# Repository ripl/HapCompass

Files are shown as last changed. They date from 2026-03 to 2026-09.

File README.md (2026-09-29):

<div align="center">
  <h1>HapCompass: A Rotational Haptic Device for Contact-Rich Robotic Teleoperation</h1>

  <p>
    <a href="https://vincent-tann.github.io">Xiangshan Tan</a><sup>1</sup>,
    <a href="https://scholar.google.com/citations?user=DeQM4Z4AAAAJ&hl=en">Jingtian Ji</a><sup>1</sup>,
    <a href="http://tianchong-jiang.github.io/">Tianchong Jiang</a><sup>1</sup>,
    <a href="https://plopes.org/">Pedro Lopes</a><sup>2</sup>,
    <a href="https://home.ttic.edu/~mwalter/">Matthew R. Walter</a><sup>1</sup>
  </p>

  <p>
    <sup>1</sup>Toyota Technological Institute at Chicago (TTIC),
    <sup>2</sup>University of Chicago
  </p>

  <p><em>ICRA 2026</em></p>

  <p>
    <a href="https://ripl.github.io/HapCompass/">Project Page</a> |
    <a href="https://arxiv.org/abs/2603.30042">Paper</a> |
    <a href="https://github.com/ripl/HapCompass/tree/main/hardware">Hardware</a>
  </p>
</div>

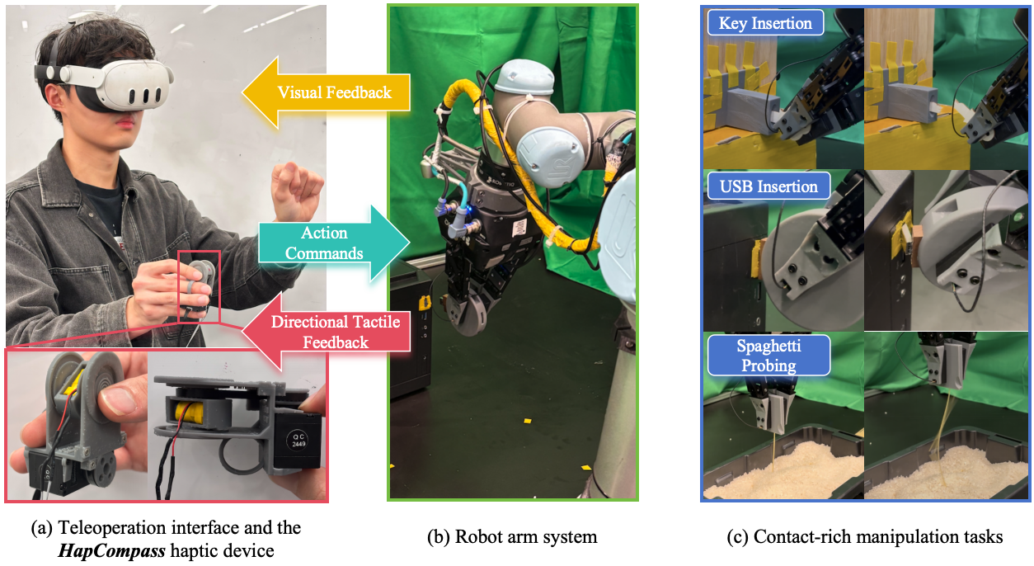
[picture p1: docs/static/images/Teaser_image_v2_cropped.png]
HapCompass teaser


## Overview
***HapCompass*** is a wearable haptic device for contact-rich robotic teleoperation that renders 2D directional cues by **mechanically rotating a single linear resonant actuator (LRA)**, whose asymmetric vibration provides directional haptic feedback. By mapping the robot's tactile measurements into directional feedback for the operator, it improves teleoperation performance on contact-rich tasks and leads to higher-quality demonstrations for imitation learning.

## TODO

### Webpage

- [x] ~~Build the project webpage~~
- [x] ~~Upload a policy rollout video~~
- [x] ~~Add an arXiv link~~

### Hardware

- [x] ~~Upload the Fusion source design and STL files~~
- [x] ~~Write BOM~~
- [x] ~~Write assembly instructions~~
<!-- - [ ] Write "Modifying Source Design" -->

<!--
### Software

- [ ] Upload the code for device control
- [ ] Upload the code for tactile mapping
- [ ] Upload the code for teleoperation
-->

## Hardware

Bill of materials (BOM), assembly instructions, editable source design (.f3z), and printable parts (.stl) can be found in the [`hardware/`](hardware/) directory.

## BibTeX

```bibtex
@inproceedings{tan2026hapcompass,
  author    = {Tan, Xiangshan and Ji, Jingtian and Jiang, Tianchong and Lopes, Pedro and Walter, Matthew R.},
  title     = {HapCompass: A Rotational Haptic Device for Contact-Rich Robotic Teleoperation},
  booktitle = {Proceedings of the IEEE International Conference on Robotics and Automation (ICRA)},
  year      = {2026},
}
```

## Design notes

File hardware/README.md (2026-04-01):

## Contents

- [Introduction](#introduction)
- [Bill of Materials (BOM)](#bill-of-materials-bom)
- [3D Printing Parts](#3d-printing-parts)
- [Critical Dimensions](#critical-dimensions)
- [Mechanical Assembly](#mechanical-assembly)
- [Electronic Assembly](#electronic-assembly)
- [Modifying the Source Design](#modifying-the-source-design)

## Introduction

This document provides the hardware documentation for HapCompass.
Please note that we made slight modifications to the version described in the paper to improve the mechanical stability of the device.

## Bill of Materials (BOM)

<table>
  <tr>
    <th>Name</th>
    <th>Quantity</th>
    <th>Specifications</th>
    <th>Image</th>
    <th>Link</th>
    <th>Price (USD)</th>
    <th>Notes</th>
  </tr>
  <tr>
    <td>LRA</td>
    <td>1</td>
    <td>Titan Haptics TacHammer DRAKE LFi (4ohm)</td>
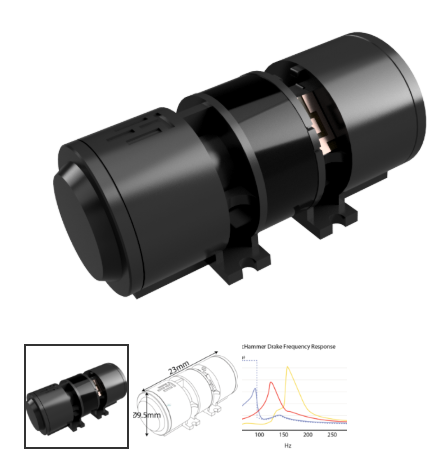
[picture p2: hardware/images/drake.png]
    <td></td>
    <td><a href="https://titanhaptics.com/drake/">Product Link</a></td>
    <td>$180/4 pieces</td>
    <td></td>
  </tr>
  <tr>
    <td>Servo Motor</td>
    <td>1</td>
    <td>Dynamixel XL330-M077-T</td>
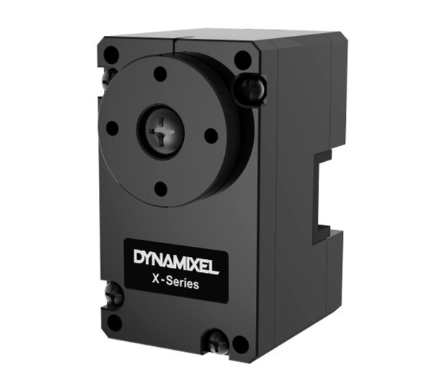
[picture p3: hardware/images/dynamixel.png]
    <td></td>
    <td><a href="https://robotis.us/dynamixel-xl330-m077-t/">Product Link</a></td>
    <td>$27.49</td>
    <td></td>
  </tr>
  <tr>
    <td>Driving Belt</td>
    <td>1</td>
    <td>MXL trade size, width 1/8'', outer circle 5.6'', 70 teeth, pitch 0.08''
    <td></td>
    <td><a href="https://www.mcmaster.com/products/1679k71/">Product Link</a></td>
    <td>$1.63</td>
    <td></td>
  </tr>
  <tr>
    <td>Ball Bearing</td>
    <td>2</td>
    <td>Inner diameter 5mm, outer diameter 8mm, width 2.5mm</td>
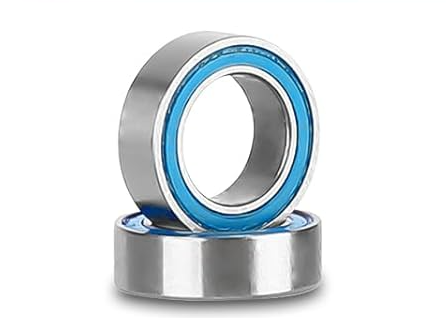
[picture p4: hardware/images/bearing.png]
    <td></td>
    <td><a href="https://www.amazon.com/dp/B0DNT3ZKY6">Product Link</a></td>
    <td>$14/1 pack</td>
    <td></td>
  </tr>
  <tr>
    <td>O-ring</td>
    <td>2</td>
    <td>Inner diameter 20mm, outer diameter 22mm, width 1mm</td>
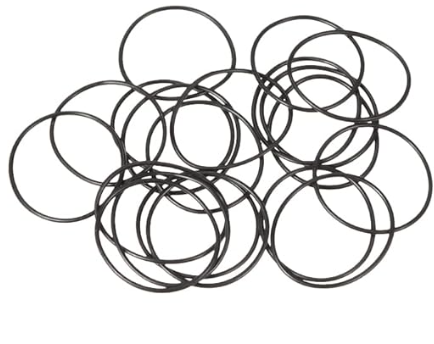
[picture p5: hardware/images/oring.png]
    <td></td>
    <!-- <td><a href="https://www.amazon.com/dp/B07FRCKJQG?th=1">Product Link</a></td> -->
    <td><a href="https://www.amazon.com/uxcell-22mmx1mm-Nitrile-Resistant-Grommets/dp/B01N8RPR5X">Product Link</a></td>
    <!-- <td>$7.09/1 pack</td> -->
    <td>$6.49/1 pack</td>
    <td>Optional</td>
  </tr>
  <tr>
    <td>Screws & Nuts</td>
    <td>3</td>
    <td>M2*4mm</td>
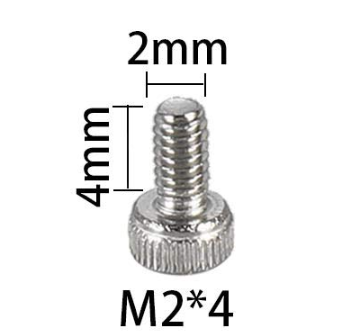
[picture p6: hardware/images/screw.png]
    <td></td>
    <td><a href=https://www.amazon.com/HanTof-Washers-Assortment-Machine-Stainless/dp/B082XRX17Z?th=1">Product Link</a></td>
    <td>-</td>
    <td></td>
  </tr>
  <tr>
    <td>Audio Amplifier Board</td>
    <td>1</td>
    <td>PAM8406 Amplifier Board 5V</td>
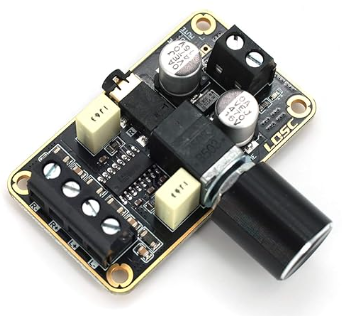
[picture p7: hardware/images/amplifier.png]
    <td></td>
    <td><a href="https://www.amazon.com/DEVMO-Amplifier-PAM8406-Digital-Channel/dp/B0899X1Y5X/?th=1">Product Link</a></td>
    <td>$13</td>
    <td></td>
  </tr>
  <tr>
    <td>Servo Driver Board</td>
    <td>1</td>
    <td>Waveshare Serial Bus Servo Driver Board</td>
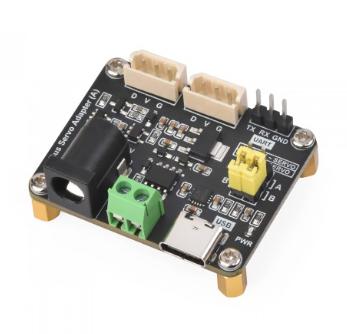
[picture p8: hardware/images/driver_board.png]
    <td></td>
    <td><a href="https://www.waveshare.com/product/bus-servo-adapter-a.htm">Product Link</a></td>
    <td>$5</td>
    <td></td>
  </tr>
</table>

## 3D Printing Parts

We printed all parts using a Formlabs Form 3 printer (using Grey resin material, 0.050mm layer thickness). We provide the `.stl` files of all parts under [`stl/`](stl/) folder.

<table>
  <tr>
    <th>Name</th>
    <th>Quantity</th>
    <th>stl file</th>
    <th>Image</th>
  </tr>
  <tr>
    <td>Rotor</td>
    <td>1</td>
    <td><a href="./stl/Rotor_bare_pulley.stl">Rotor_bare_pulley.stl</a></td>
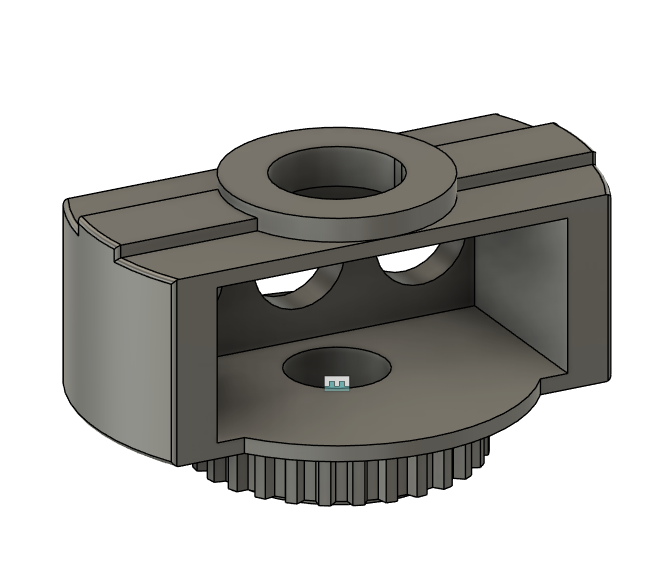
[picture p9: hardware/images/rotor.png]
    <td></td>
  </tr>

  <tr>
    <td>Motor Pulley</td>
    <td>1</td>
    <td><a href="./stl/Motor_Pulley.stl">Motor_Pulley.stl</a></td>
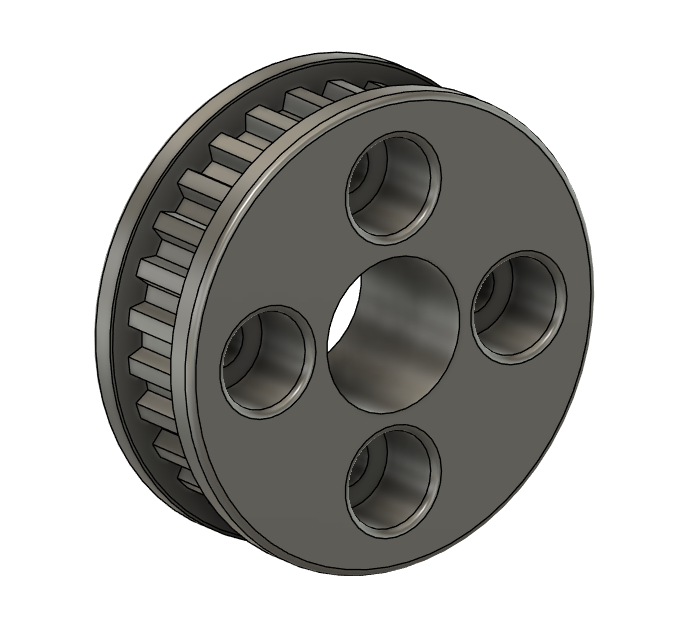
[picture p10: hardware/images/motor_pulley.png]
    <td></td>
  </tr>

  <tr>
    <td>Shell - Upper Outer</td>
    <td>1</td>
    <td><a href="./stl/Shell_upper_outside.stl">Shell_upper_outside.stl</a></td>
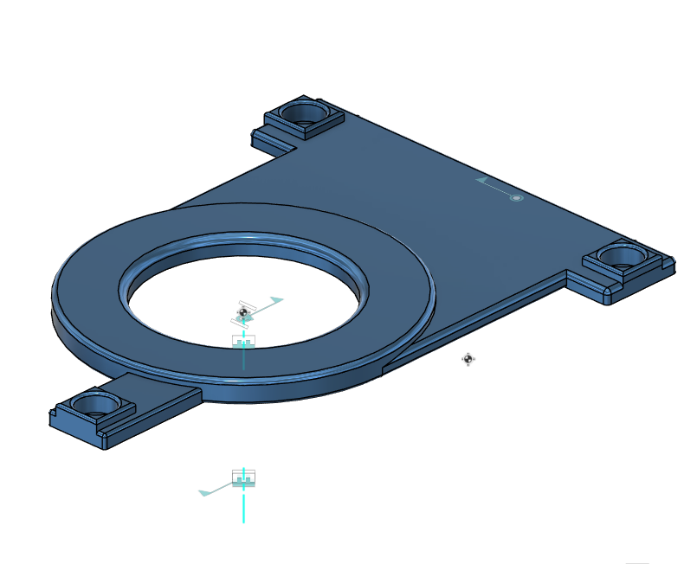
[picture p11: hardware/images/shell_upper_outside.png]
    <td></td>
  </tr>

  <tr>
    <td>Shell - Upper Inner</td>
    <td>1</td>
    <td><a href="./stl/Shell_upper_inside.stl">Shell_upper_inside.stl</a></td>
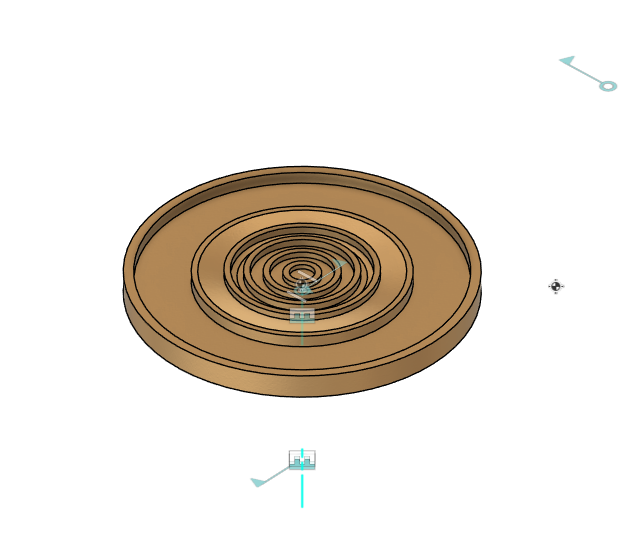
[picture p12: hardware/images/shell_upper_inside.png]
    <td></td>
  </tr>

  <tr>
    <td>Shell - Bottom Outer</td>
    <td>1</td>
    <td><a href="./stl/Shell-bottom-outside.stl">Shell-bottom-outside.stl</a></td>
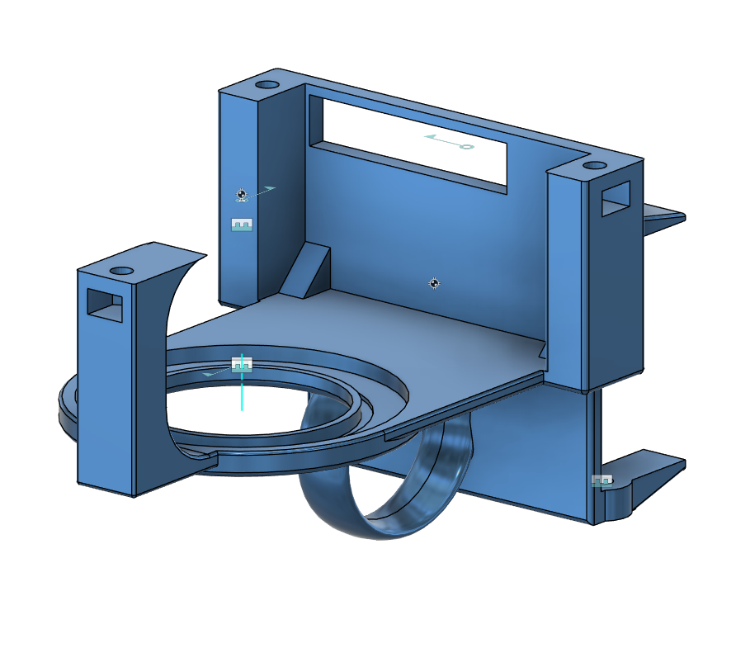
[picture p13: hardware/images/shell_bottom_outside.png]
    <td></td>
  </tr>

  <tr>
    <td>Shell - Bottom Inner</td>
    <td>1</td>
    <td><a href="./stl/Shell-bottom-inside.stl">Shell-bottom-inside.stl</a></td>
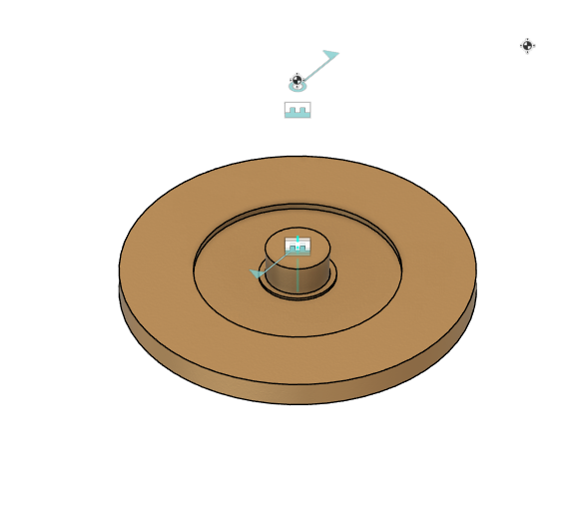
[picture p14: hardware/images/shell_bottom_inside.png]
    <td></td>
  </tr>
</table>

## Critical Dimensions

Some dimensions of the HapCompass are critical to vibration transmission. If the fit is too tight, the device may be difficult or impossible to assemble; if it is too loose, a significant portion of the vibration energy may dissipate before reaching the user's fingertip.

The effective vibration transmission path is: 
- LRA -> Rotor -> Ball Bearings -> Inner Shells (yellow) -> Fingertip

Therefore, the dimensions shown in the figure below are critical to vibration transmission:

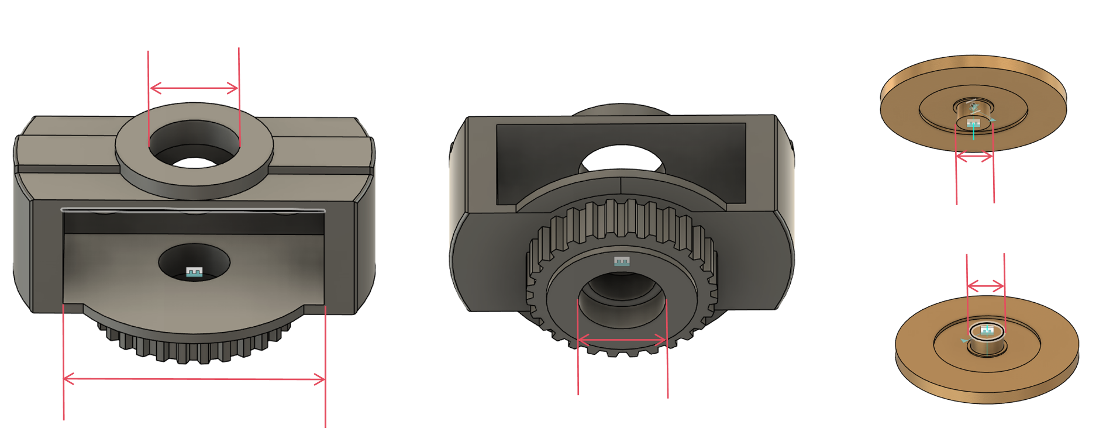
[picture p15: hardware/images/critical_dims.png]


Due to hardware variations, such as differences between 3D printers or slight variations in bearing diameter, you *might* need to adjust these dimensions. If you find that:
- the fit is so tight that assembly is almost impossible; or
- the fit is loose enough that some parts can move slightly along these dimensions (for example, the LRA can move slightly along its vibration axis inside the rotor),

then you can adjust these dimensions by [modifying the source design](#modifying-the-source-design).

## Mechanical Assembly

Step 1: Attach the two bearings and the two inner shells to the rotor.

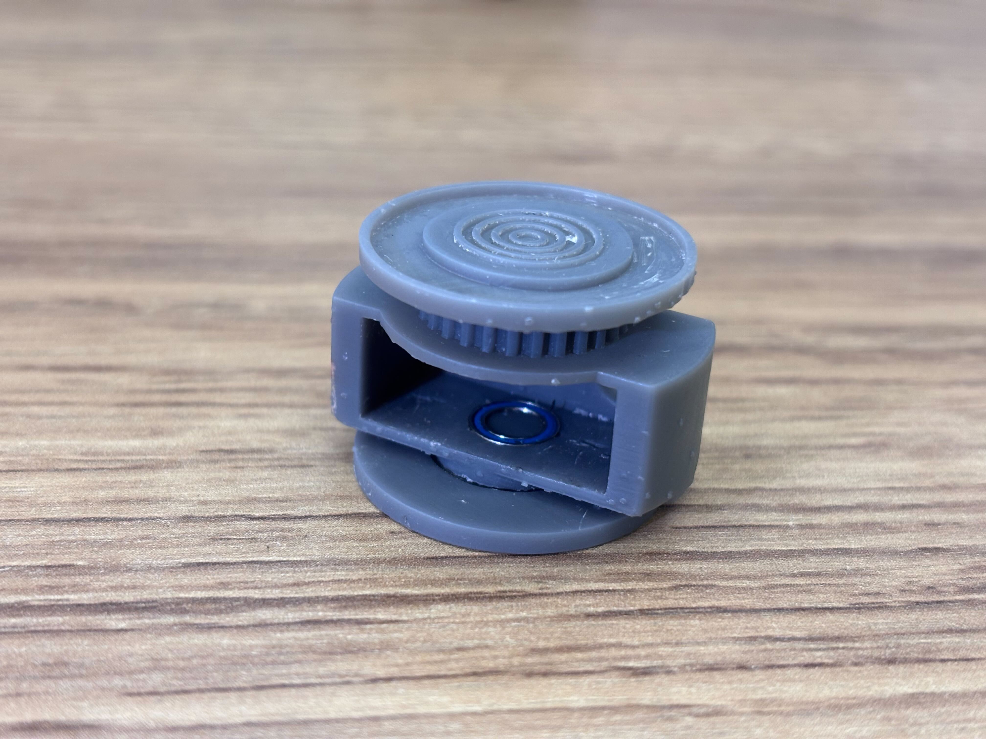
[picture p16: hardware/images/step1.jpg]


Step 2: Attach the motor pulley to the servo motor (using the short screws from the servo package).

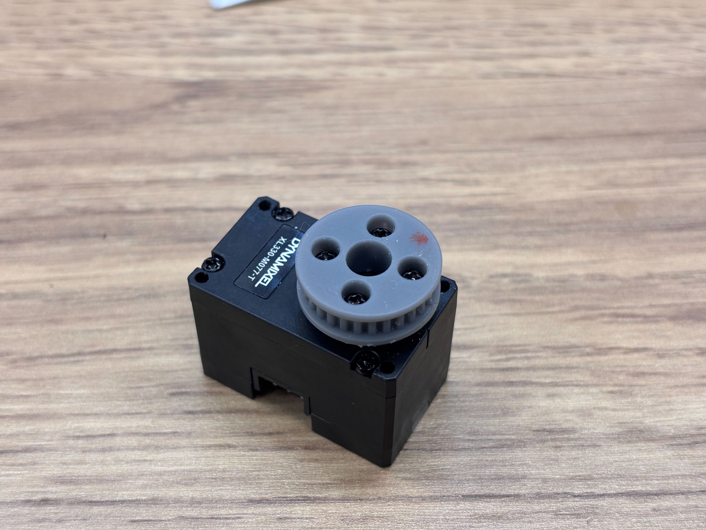
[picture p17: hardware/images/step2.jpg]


Step 3: Pass the driving belt through the long slot in the shell, then mount the servo to the shell (using the long screws from the servo package).

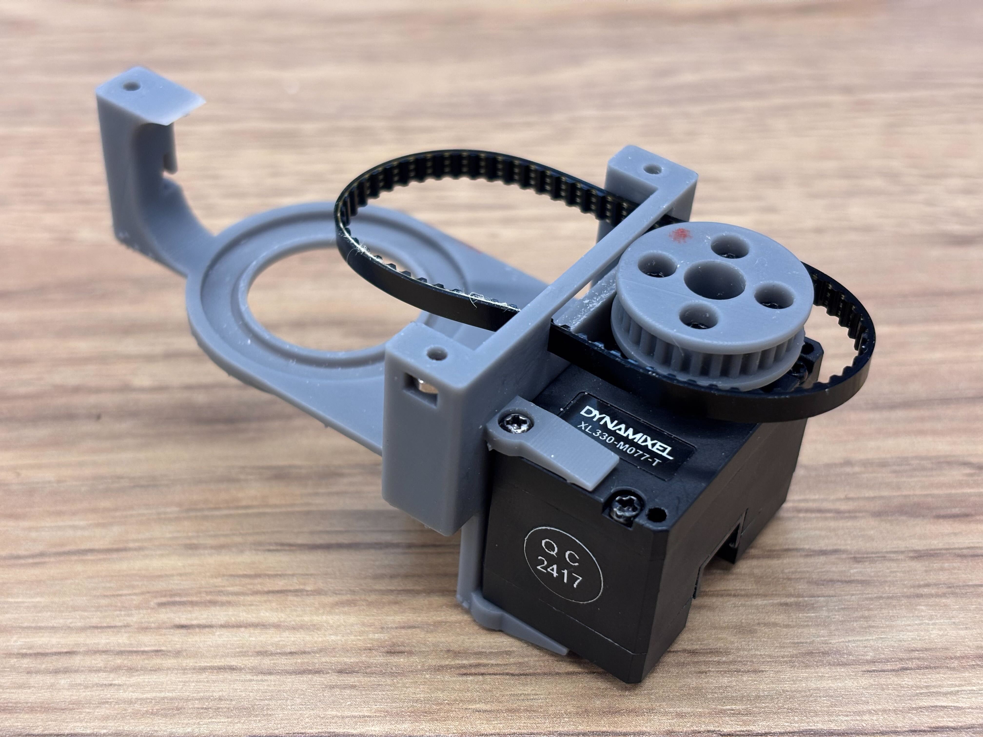
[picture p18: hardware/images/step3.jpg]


Step 4 (Optional): install the two rubber O-rings to the outer shells. This step may be easier if you use tweezers and a small amount of glue.

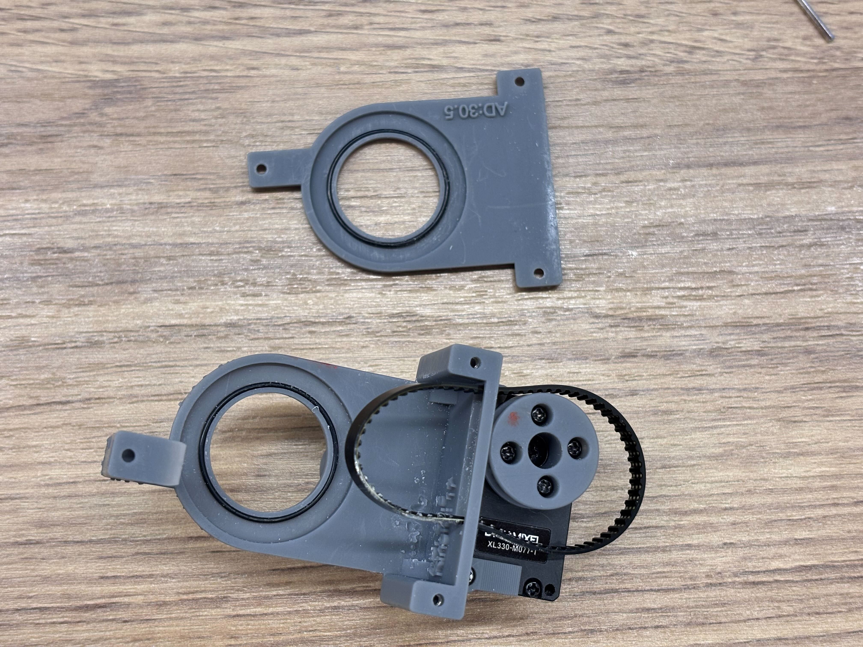
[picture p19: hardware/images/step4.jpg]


Step 5: Fit the belt around the pulley and the rotor.

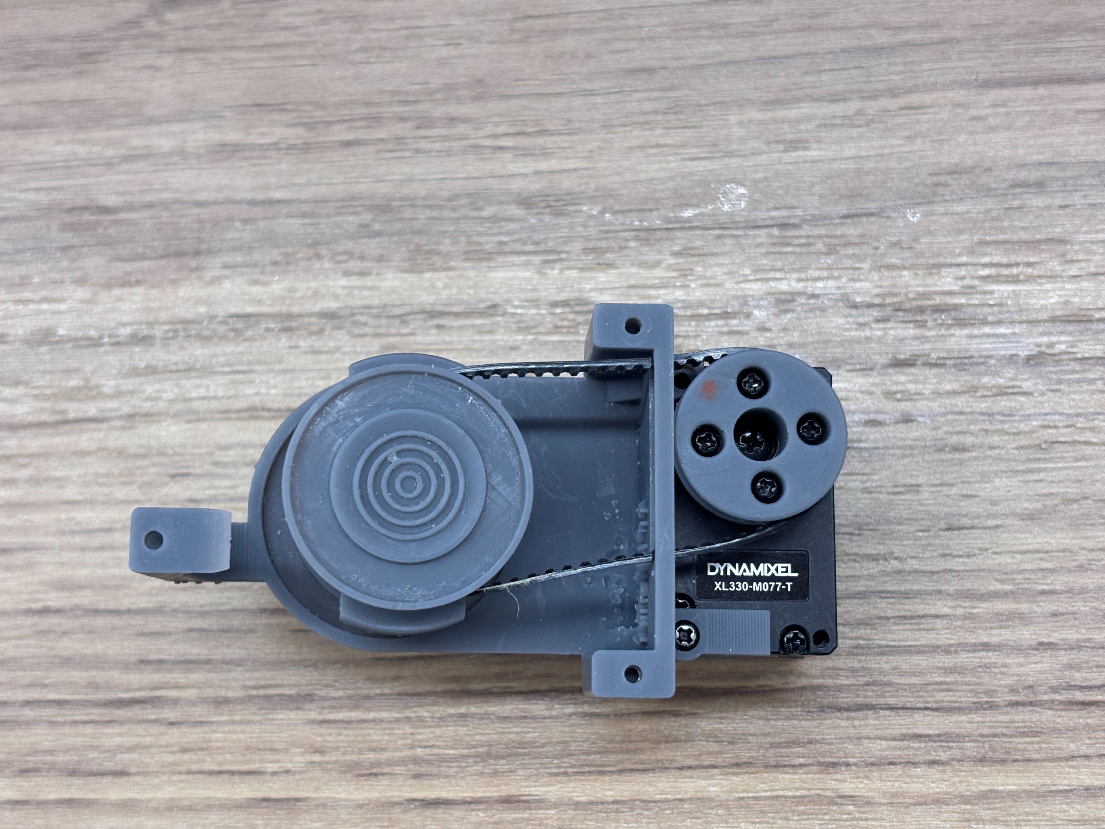
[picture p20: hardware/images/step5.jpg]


Step 6: Assemble the upper shell and the bottom shell using screws and nuts.

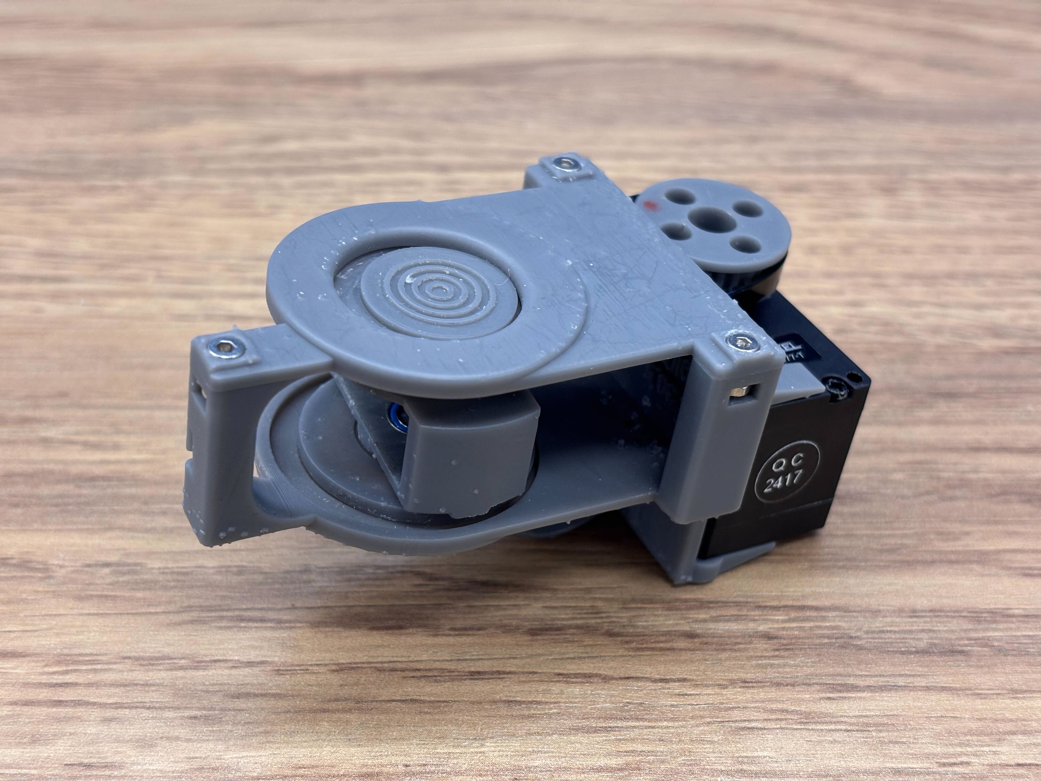
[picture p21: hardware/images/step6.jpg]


## Electronic Assembly

Step 1: The wires on the Drake actuator (LRA) are very short when purchased (left), so extend them by soldering on additional wire (right).



Step 2: Install the LRA into the rotor. The arrow indicates the direction of the pulling sensation produced by the asymmetric vibration.

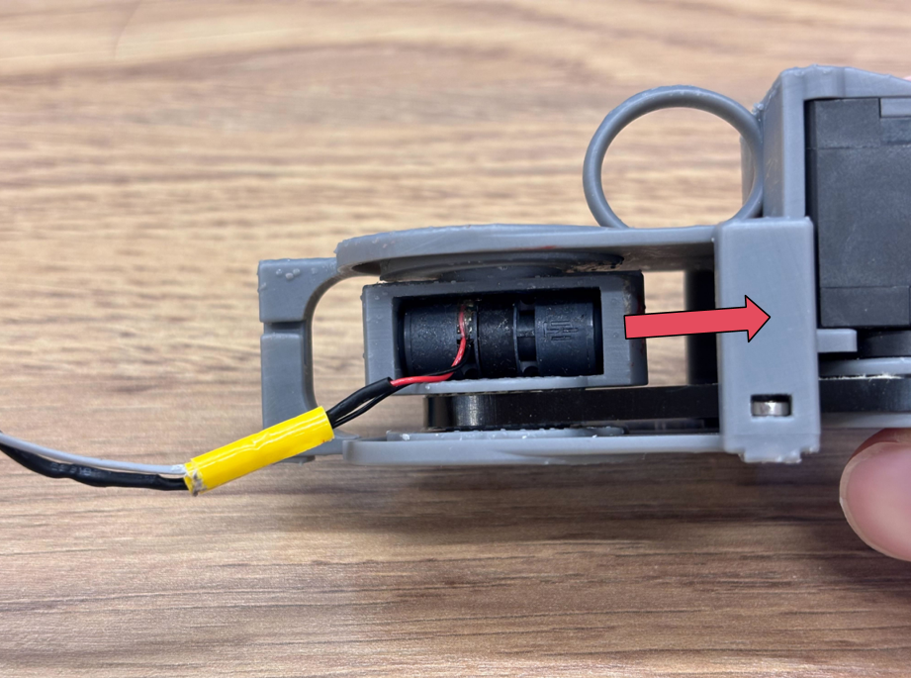
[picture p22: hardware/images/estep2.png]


Step 3: Connect the LRA wires to the right-channel output of the audio amplifier board, making sure to observe the correct polarity. Connect the board to the PC's speaker output using a 3.5 mm audio cable, and connect a 5 V power supply to the board.

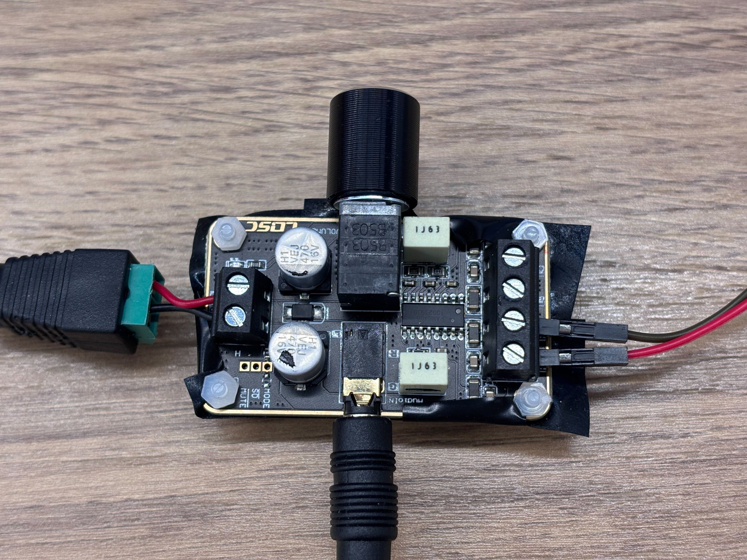
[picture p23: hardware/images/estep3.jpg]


Step 4: Connect the servo to the driver board with extended wires. For connector details, see the [XL330-M077 Connector Information](https://emanual.robotis.com/docs/en/dxl/x/xl330-m077/#connector-information). Then connect the board to the PC using a USB-C cable, and connect a 5 V power supply to the board.

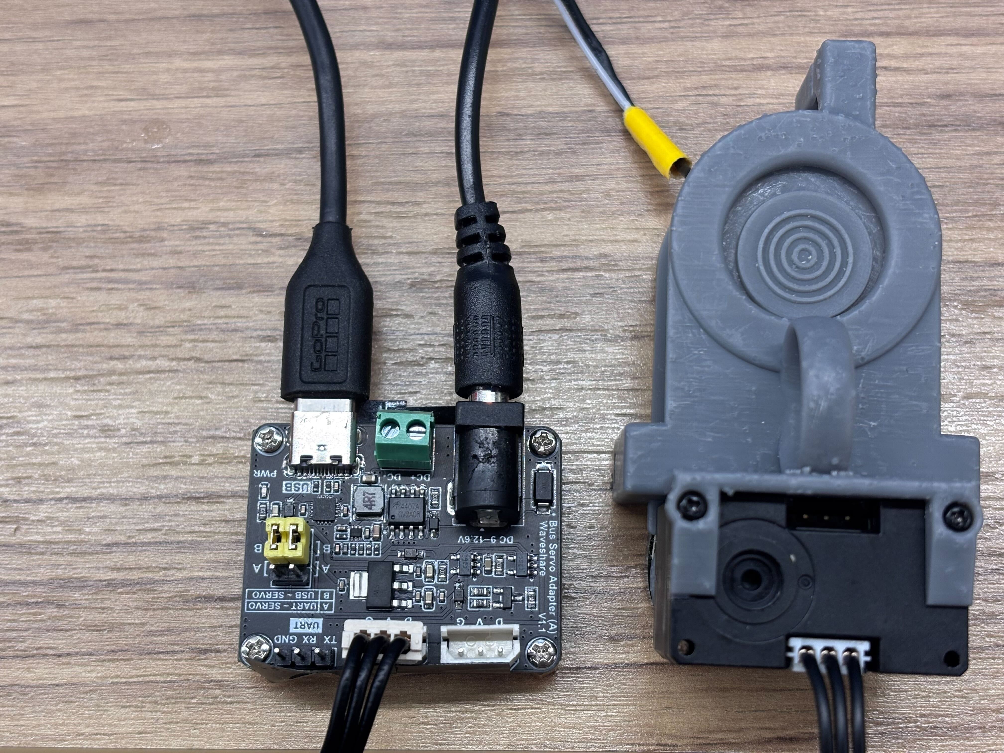
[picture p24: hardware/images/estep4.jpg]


## Modifying the Source Design
Coming soon.

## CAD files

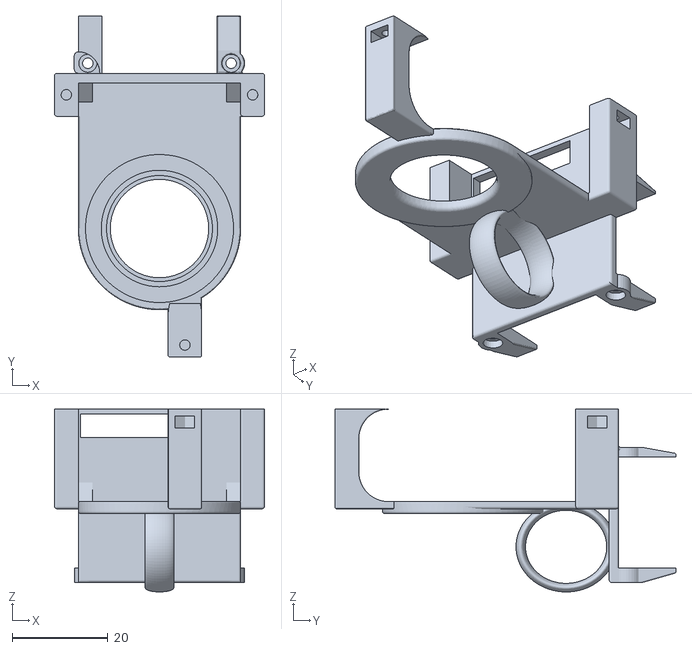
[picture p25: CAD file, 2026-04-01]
hardware/stl/Shell-bottom-outside.stl
44.0 x 71.4 x 38.3

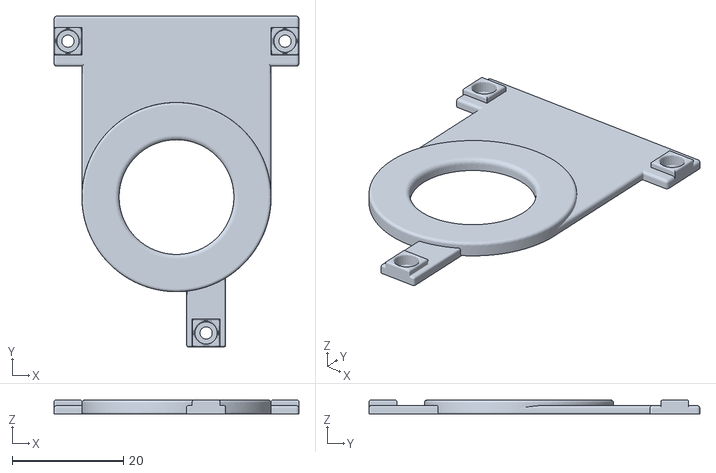
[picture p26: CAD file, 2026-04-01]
hardware/stl/Shell_upper_outside.stl
44.0 x 59.4 x 2.50

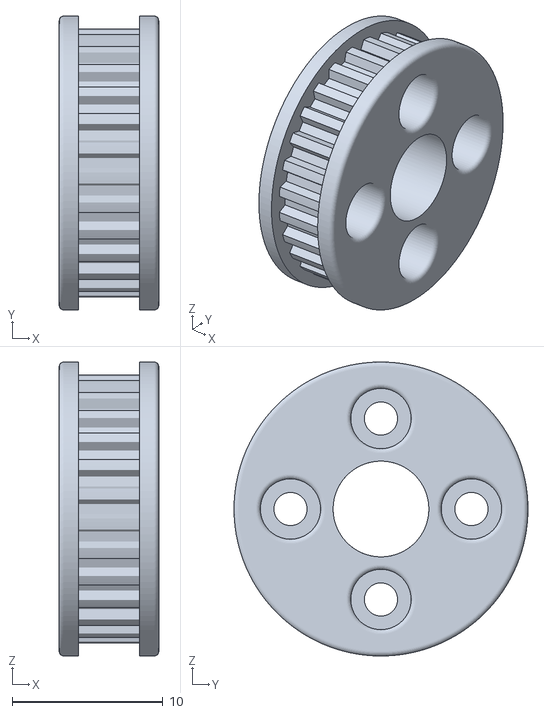
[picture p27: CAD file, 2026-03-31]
hardware/stl/Motor_Pulley.stl
6.60 x 19.5 x 19.5

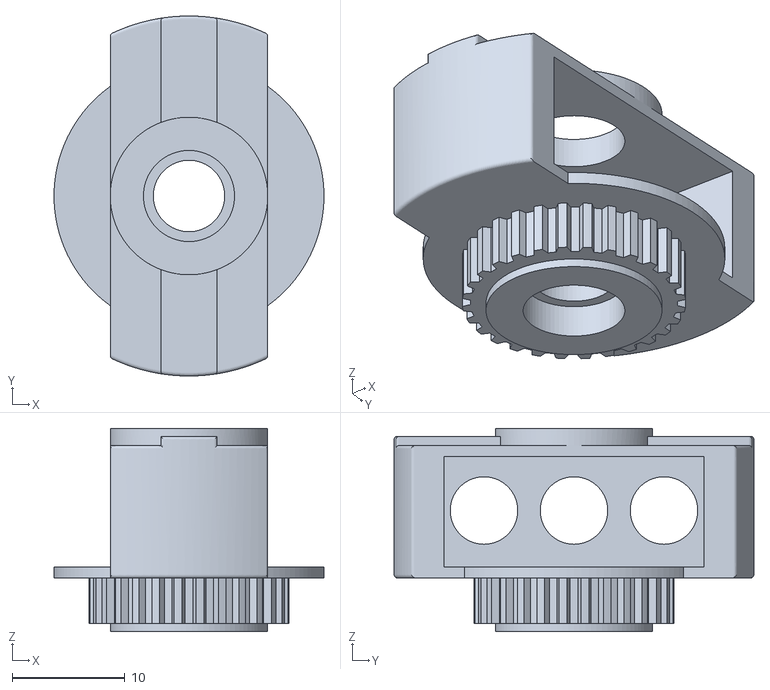
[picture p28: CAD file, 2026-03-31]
hardware/stl/Rotor_bare_pulley.stl
24.0 x 32.0 x 18.1

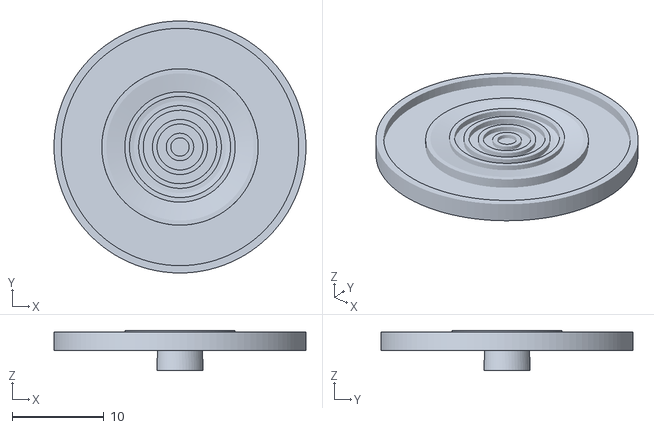
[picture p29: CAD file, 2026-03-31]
hardware/stl/Shell_upper_inside.stl
27.4 x 27.4 x 4.40

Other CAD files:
hardware/stl/Shell-bottom-inside.stl
hardware/fusion/HapCompass.f3z

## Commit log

2026-03-31 hardware: upload device source design file and stl files.
    [HapCompass v0.2.f3z, Motor Pulley.stl, Rotor_bare_pulley.stl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]
2026-03-31 doc: write BOM
2026-04-01 hardware: update source design file
    [HapCompass v0.2.f3z, HapCompass.f3z]
2026-04-01 doc: write hardware assembly instructions
    [Motor Pulley.stl, Motor_Pulley.stl]
2026-04-01 hardware: update stl files of the two outer shells
    [Shell-bottom-outside.stl, Shell_upper_outside.stl]
